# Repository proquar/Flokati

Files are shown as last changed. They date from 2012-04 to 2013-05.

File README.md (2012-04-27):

Flokati
=======

Flokati is a collaborative ad-hoc automation system consisting of a
(relatively) low-speed rf-part based on AVR-microcontrollers and Nordic's
NRF-ICs, an OpenWrt-based WiFi-Gateway and an Android-App as a frontend.

For convenience the Android-App and OpenWrt-package for ar71xx are provided
in binary too.

History / Motivation / Overview
===============================

The original idea was to build a system of battery-powered devices for off-
the-grid outdoor parties, it should be:
* absolutely easy to set up and to use
* fast and responsive
* used simultaneously by a few people (and be robust at that)
* relatively cheap to build

Overall it already works very well, it still has some shortcomings, but I am
working on those.

Flokati-Parts
-------------

**Devices**

*	Currently there are only some spotlights and a mirror ball motor that I
	built around the Atmega88 and NRF24L01+.
	Devices have a unique 64bit address and can have multiple controllable
	elements (e.g. brightness, speed).
	Devices use Nordic's proprietary 2.4GHz NRF-technology (which was chosen
	because it is really cheap, much cheaper than e.g. 802.15.4).

**Gateway**

*	There needs to be a bridge between the IP-world and the proprietary
	rf-world. Here it is an OpenWrt-based WiFi access point (a battery powered
	TP-Link MR11U in my case) that also acts as a DCHP-server and hosts the
	device database.

**Frontend**

*	At the moment there's only the Android-App, which discovers new devices,
	requests device metadata from the device database and allows low-level
	control of discovered devices.

Architecture
------------

On the IP-side Flokati makes heavy use of IP-multicast. The bridge and the
Android devices all join a multicast group, and changes on one Android device
are immediately visible on the others. All actions on either side (NRF and IP)
are as fast as possible broadcast to the other side.

Controllable devices broadcast notify-messages with their ID and current
settings regularly, which are received by the frontend. The frontend then looks
up metadata (like name and controllable sinks) for that device from a database
which is also distributed in a multicast group. (Though the database currently
runs on the OpenWrt gateway and is not yet distributed)

So it is also possible to have controllable devices on the IP-side, so there
are currently no implementations for this. I will also add a mechanism for
remote configuration of some devices in the near future.

Directories
===========

**/avr**

*	These are some small devices I have built, there's a spotlight, which is
	able to PWM-dim or strobe a led. A mirror ball motor with controllable
	speed and direction. And the serial<->NRF gateway that is attached to the
	OpenWrt router.
	I will add hardware schematics and board layouts later.

**/Flokati-android**

*	This is the Android App as an Eclipse project. It's tiny and without any
	additional libraries. 

**/json-db**

*	Device metadata currently used by the database server on the OpenWrt
	router. Temporary solution. Should be put into /etc/flokati/db.

**/linux/flokati**

*	This is the OpenWrt package, consisting of two server-executables (bridge
	and database) and an init-script. The bridge can indicate it's status with
	a LED, that can be configured in the init-script.

**/flokati/python**

*	A few python tools, that I used during development. They do the same as the
	C-servers for OpenWrt.

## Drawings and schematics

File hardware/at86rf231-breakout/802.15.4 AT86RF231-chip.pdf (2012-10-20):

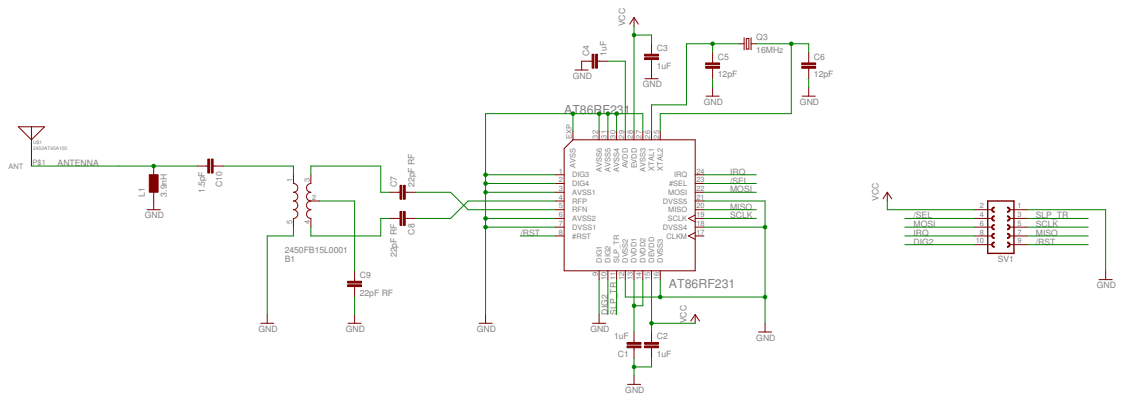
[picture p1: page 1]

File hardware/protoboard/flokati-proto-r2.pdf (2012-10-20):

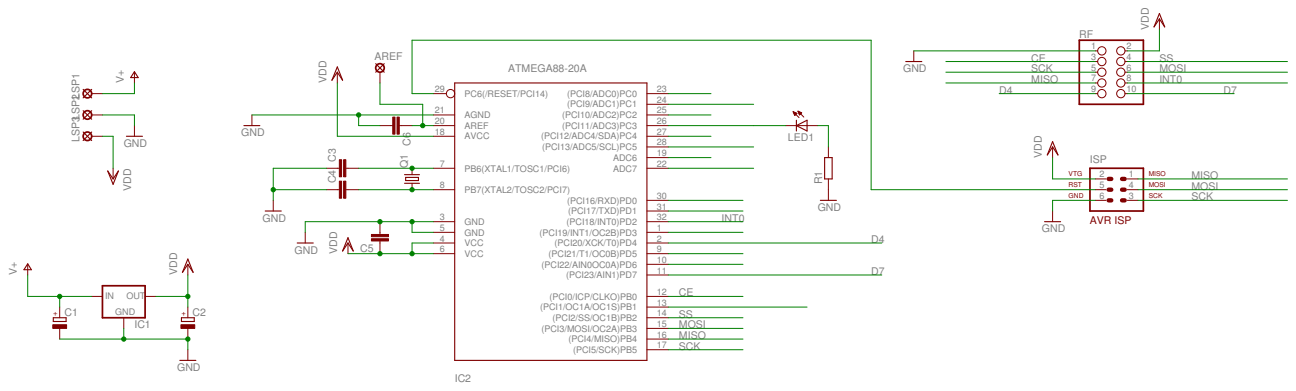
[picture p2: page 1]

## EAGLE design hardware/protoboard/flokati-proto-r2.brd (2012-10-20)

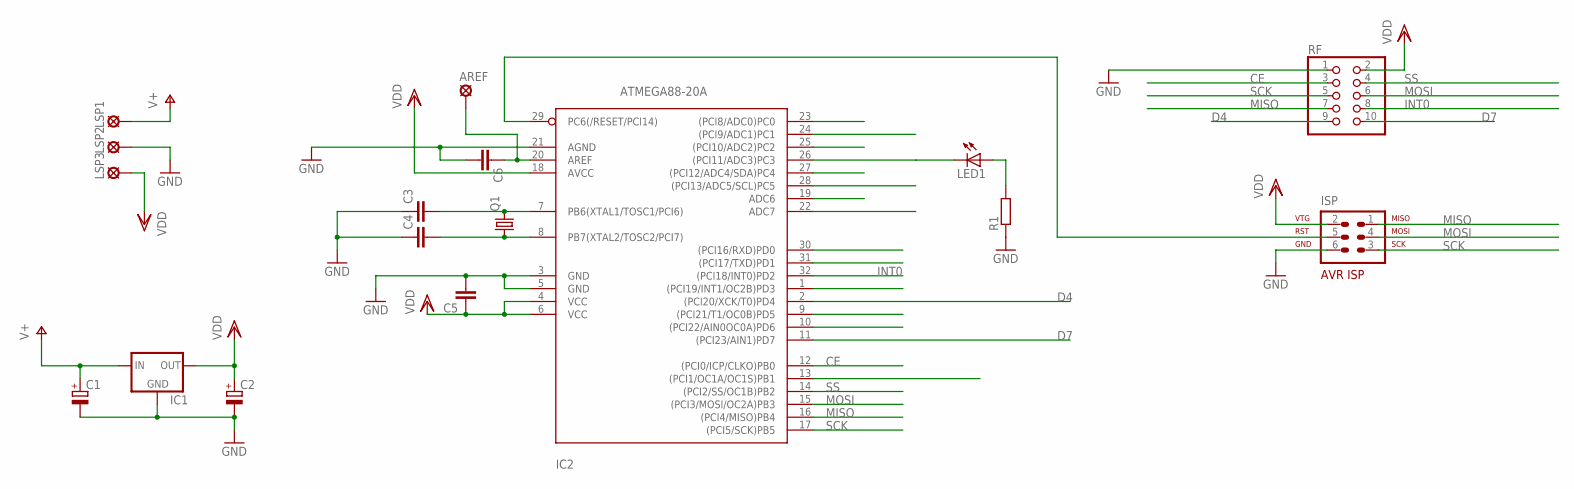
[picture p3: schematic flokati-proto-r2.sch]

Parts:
AREF: LSP10
C1, C2: CPOL-EUE2-4; E2-4
C3, C4, C5, C6: C-EUC0805K; C0805K
IC1: 78XXS
IC2: ATMEGA88-20A; TQFP32-08
ISP: AVR-ISP-6
LED1: LEDCHIP-LED0805; CHIP-LED0805
LSP1, LSP2, LSP3: LSP11
Q1: CRYSTALHC49U70; HC49U70
R1: R-EU_M0805; M0805
RF: PINHD-2X5; 2X05

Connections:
CE: IC2.12 ((PCI0/ICP/CLKO)PB0), RF.3
D4: IC2.2 ((PCI20/XCK/T0)PD4), RF.9
D7: IC2.11 ((PCI23/AIN1)PD7), RF.10
GND: C1.-, C2.-, C3.1, C4.1, C5.2, C6.2, IC1.GND, IC2.3 (GND), IC2.5 (GND), IC2.21 (AGND), ISP.6, LSP2.MP, R1.1, RF.1
INT0: IC2.32 ((PCI18/INT0)PD2), RF.8
MISO: IC2.16 ((PCI4/MISO)PB4), ISP.1, RF.7
MOSI: IC2.15 ((PCI3/MOSI/OC2A)PB3), ISP.4, RF.6
unnamed: C3.2, IC2.7 (PB6(XTAL1/TOSC1/PCI6)), Q1.2
unnamed: C4.2, IC2.8 (PB7(XTAL2/TOSC2/PCI7)), Q1.1
unnamed: AREF.MP, C6.1, IC2.20 (AREF)
unnamed: IC2.29 (PC6(/RESET/PCI14)), ISP.5
unnamed: IC2.26 ((PCI11/ADC3)PC3), LED1.C
unnamed: LED1.A, R1.2
SCK: IC2.17 ((PCI5/SCK)PB5), ISP.3, RF.5
SS: IC2.14 ((PCI2/SS/OC1B)PB2), RF.4
V+: C1.+, IC1.IN, LSP1.MP
VDD: C2.+, C5.1, IC1.OUT, IC2.4 (VCC), IC2.6 (VCC), IC2.18 (AVCC), ISP.2, LSP3.MP, RF.2

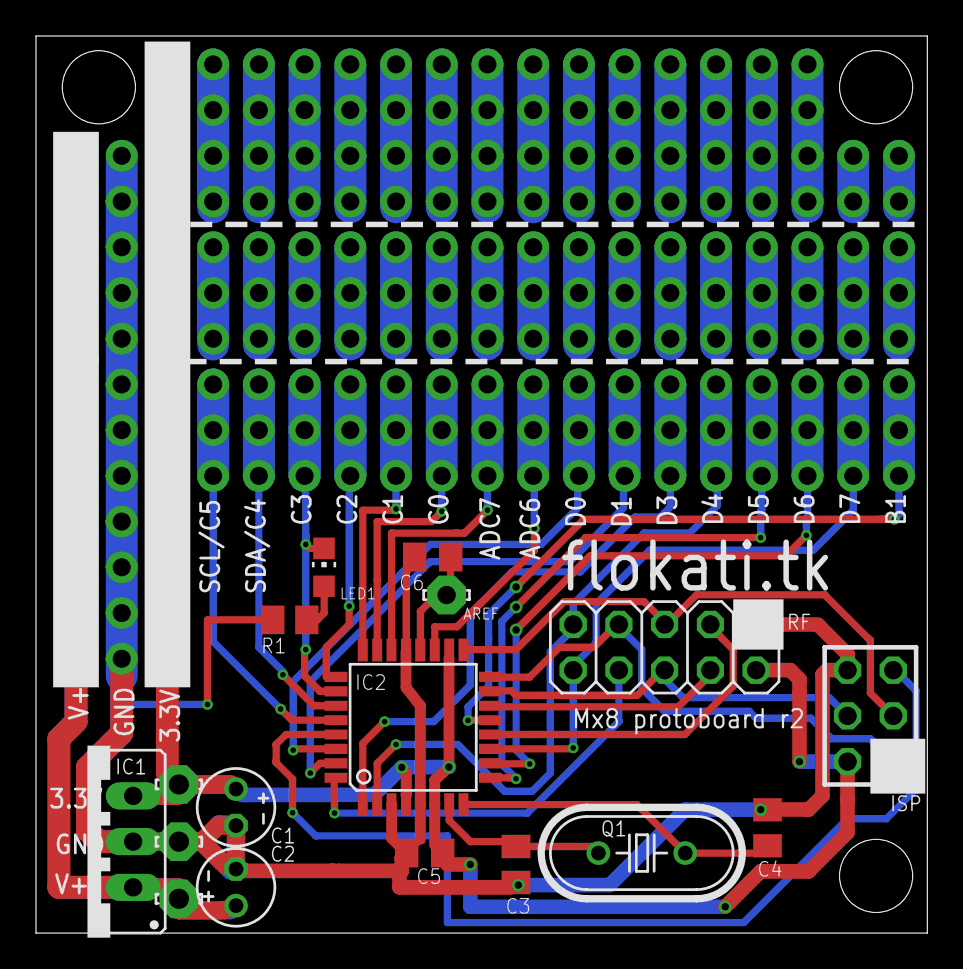
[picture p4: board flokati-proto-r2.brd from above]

Board: 2 copper layers, 49.5 x 49.8 mm, 17 parts (0 on the bottom side), 17 nets.

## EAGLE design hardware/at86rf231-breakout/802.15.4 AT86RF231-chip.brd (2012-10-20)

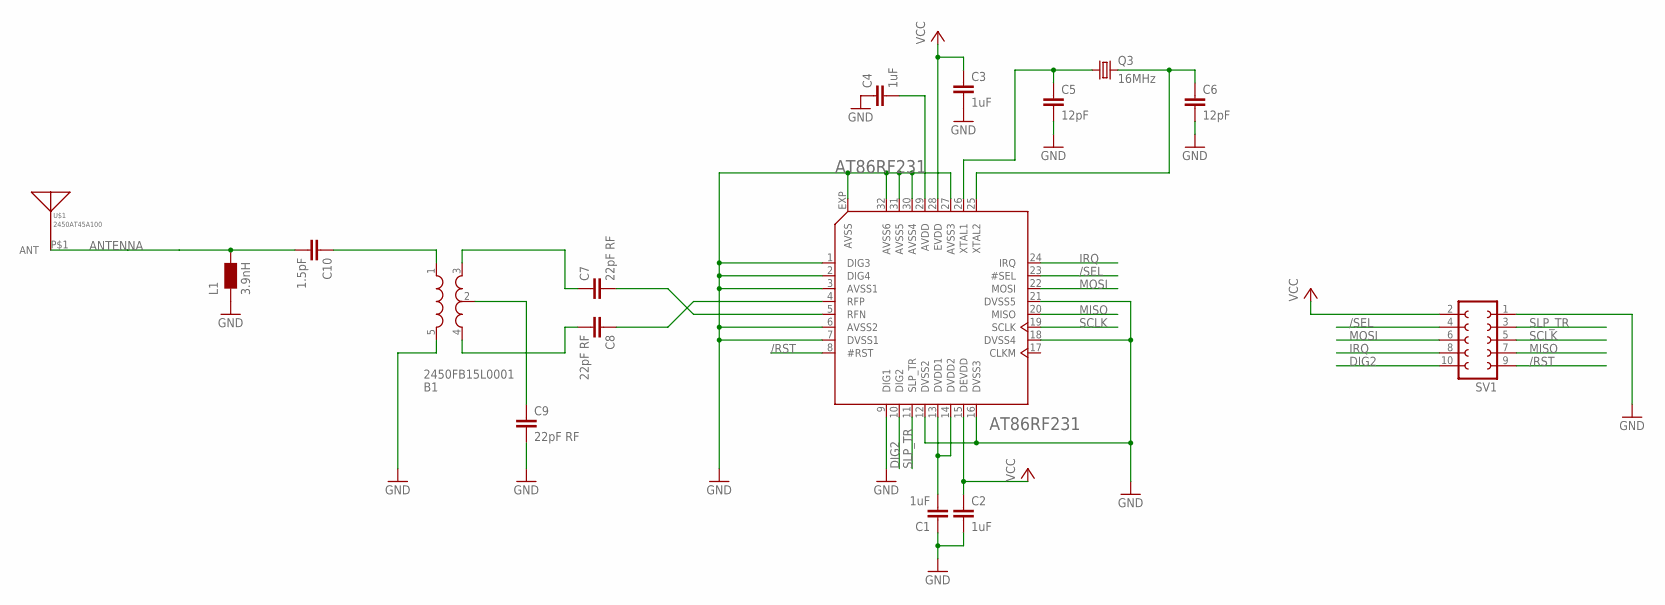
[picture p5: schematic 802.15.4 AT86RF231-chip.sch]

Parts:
AT86RF231: AT86RF231; QFN32
B1: 2450FB15L0001; BALUN
C1, C2, C3, C4: 1uF; C0402K
C5, C6: 12pF; C0402K
C7, C8, C9: 22pF RF; C0402K
C10: 1.5pF; C0402K
L1: 3.9nH; 0402
Q3: 16MHz; CTS406
SV1: FE05-2
U$1: 2450AT45A100

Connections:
/RST: AT86RF231.8 (#RST), SV1.9
/SEL: AT86RF231.23 (#SEL), SV1.4
ANTENNA: C10.2, L1.2, U$1.P$1
AVDD: AT86RF231.29 (AVDD), C4.2
DIG2: AT86RF231.10 (DIG2), SV1.10
DVDD1: AT86RF231.13 (DVDD1), AT86RF231.14 (DVDD2), C1.2
GND: AT86RF231.1 (DIG3), AT86RF231.2 (DIG4), AT86RF231.3 (AVSS1), AT86RF231.6 (AVSS2), AT86RF231.7 (DVSS1), AT86RF231.9 (DIG1), AT86RF231.12 (DVSS2), AT86RF231.16 (DVSS3), AT86RF231.18 (DVSS4), AT86RF231.21 (DVSS5), AT86RF231.27 (AVSS3), AT86RF231.30 (AVSS4), AT86RF231.31 (AVSS5), AT86RF231.32 (AVSS6), AT86RF231.EXP (AVSS), B1.5 (GND), C1.1, C2.2, C3.2, C4.1, C5.2, C6.2, C9.2, L1.1, SV1.1
IRQ: AT86RF231.24 (IRQ), SV1.8
MISO: AT86RF231.20 (MISO), SV1.7
MOSI: AT86RF231.22 (MOSI), SV1.6
unnamed: AT86RF231.26 (XTAL1), C5.1, Q3.1
unnamed: AT86RF231.25 (XTAL2), C6.1, Q3.3 (2)
unnamed: AT86RF231.4 (RFP), C8.1
unnamed: AT86RF231.5 (RFN), C7.2
unnamed: B1.3 (OUT1), C7.1
unnamed: B1.4 (OUT2), C8.2
unnamed: B1.2 (GND), C9.1
unnamed: B1.1 (IN), C10.1
SCLK: AT86RF231.19 (SCLK), SV1.5
SLP_TR: AT86RF231.11 (SLP_TR), SV1.3
VCC: AT86RF231.15 (DEVDD), AT86RF231.28 (EVDD), C2.1, C3.1, SV1.2

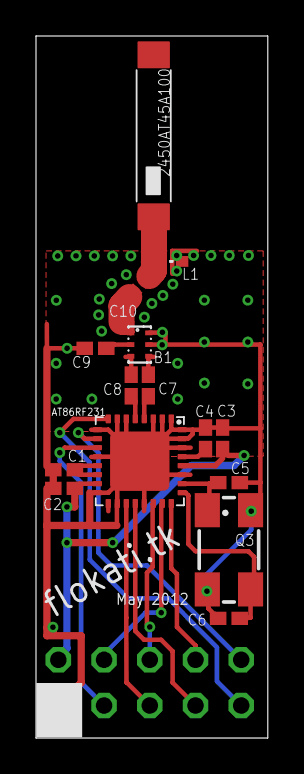
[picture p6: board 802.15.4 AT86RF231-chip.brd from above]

Board: 2 copper layers, 12.9 x 39.0 mm, 16 parts (1 on the bottom side), 21 nets.

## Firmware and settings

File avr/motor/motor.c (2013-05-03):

#include <avr/io.h>
#include <avr/interrupt.h>
#include <stdlib.h>

#include "../nrf24l01/packet.h"
#include "../nrf24l01/radio.h"
#include "../nrf24l01/common.h"

// motors have 2 sinks:
//   1: speed (16bit signed)
//   2: boost (boolean)

#define OWN_ADDRESS		"\0\0\0\x01\x00\x08\x00\x01"

// status-led
#define RXMON_INIT()	DDRC |= (1<<3)
#define RXMON_ON() 		DDRC |= (1<<3)
#define RXMON_OFF() 	DDRC &= ~(1<<3)

// Motor:	Dir1: D6, OC0A (dir1)
//			Dir2: D5, OC0B
//			EN:   C0
#define MOTOR_INIT()		PORTC&=~1; DDRC|=1; PORTD&=~((1<<5)|(1<<6)); DDRD|=((1<<5)|(1<<6))
#define MOTOR_ENABLE() 		PORTC|=1
#define MOTOR_DISABLE()		PORTC&=~1
#define MOTOR_FW_ON()		PORTD|=(1<<6)
#define MOTOR_FW_OFF()		PORTD&=~(1<<6)
#define MOTOR_RW_ON()		PORTD|=(1<<5)
#define MOTOR_RW_OFF()		PORTD&=~(1<<5)

radiopacket_t packet, notify;
volatile uint8_t newPacket=0;
volatile uint16_t nrf_reset_cnt=0;
volatile uint8_t notify_cnt=0;


volatile uint8_t direction=0;
volatile uint16_t speed=140;	// 140 = 1rpm, 230 = 2rpm, 300 = 3rpm, 370 = 4rpm,   max 500 @4.8V
volatile int16_t receivedSpeed=0;

volatile uint16_t pwmCnt=0;

volatile uint16_t boostCnt=0;
volatile int8_t boost=0;



void prepareNotify(void) {
	notify.type=NOTIFY;
	memcpy(notify.address, OWN_ADDRESS, 8);
	
	notify.data.notify.content[ 0]=0x01; //len: 2
	notify.data.notify.content[ 3]=0x02; //len: 1
	notify.data.notify.content[ 5]=0x03; //invalid sink
}
void sendNotify(void) {
	notify.data.notify.content[ 1]=receivedSpeed>>8;
	notify.data.notify.content[ 2]=receivedSpeed;
	notify.data.notify.content[ 4]=boost;
	
	Radio_Transmit(&notify, ABSOLUTE_MAXIMUM_SIZE, RADIO_WAIT_FOR_TX);
}


int main(void)
{
	RXMON_INIT();
	
	// STRATEGY:
	//     pwm is too fast for our motor, so we will just give it a short push twice a second
	//     so, we use the overflow interrupt to do our own very slow pwm
	MOTOR_INIT();
	TCCR0A = 0; 			// normal mode, no pwm
	TCCR0B = (1<<CS01);		// clk/8, enable counter
	TIMSK0 |= (1<<TOIE0);	//overflow interrupt on
	
	// Timer 2 for blinking status LED (clk/1024)
	TCCR2B = (1<<CS22)|(1<<CS21)|(1<<CS20);
	TIMSK2 |= (1<<TOIE2);
	
	// TImer 1 (clk/1024) for boost timing
	TCCR1B=(1<<CS12)|(1<<CS10);
	
	receivedSpeed=speed<<6;
	if (direction) speed *= -1;
	prepareNotify();
	
	rf_init();
	sei();

	for(;;) {		
		if ( newPacket ) {
			newPacket--;
			if ( Radio_Receive(&packet) >= RADIO_RX_MORE_PACKETS ) {
				RXMON_ON();
				
				// a real data package received
				if (packet.type==MESSAGE && (memcmp(packet.address, OWN_ADDRESS, 8)==0)) {
					
					uint8_t content_ptr=0;
					while (content_ptr<MESSAGE_CONTENT_MAX_SIZE) {
						uint8_t sink=packet.data.message.content[content_ptr];
						if (sink==1) {
							receivedSpeed = packet.data.message.content[content_ptr+1];
							receivedSpeed <<= 8;
							receivedSpeed |= packet.data.message.content[content_ptr+2];
							content_ptr+=3;
						} else if (sink==2) {
							if (packet.data.message.content[content_ptr+1] && boost<=0)
								boost = 1;
							//TODO: immediately reply with notify
							content_ptr+=2;
						} else {
							break;
						}
					}
					
					// ...
					if (receivedSpeed>=0) {
						speed=receivedSpeed>>6; //only use 9 bit (max. duty cycle 1/4)
						direction=0;
					} else {
						speed=(receivedSpeed*-1)>>6;
						direction=1;
					}
				}
			}
			
		}
		
		if (boost==-1) {
			// TODO send notify when boost is done
			boost=0;
		}
		
		if (nrf_reset_cnt>180) {
			// sometimes it seems that the nrf-chip crashes, so we re-initialise it after ~6s without receiving anything
			rf_init();
			nrf_reset_cnt=0;
		}
		
		if (notify_cnt>28) {
			sendNotify();
			notify_cnt=0;
		}
	}
	return 0;
}

ISR( TIMER0_OVF_vect ) {
	if (boost>0) {
		if (boost==1) {
			MOTOR_ENABLE();
			if (direction) { MOTOR_RW_OFF(); MOTOR_FW_ON(); }
			else { MOTOR_FW_OFF(); MOTOR_RW_ON(); }
			boostCnt=TCNT1;
			boost=2;
		}
		else if (boost==2 && (TCNT1-boostCnt)>7000) { // ~900ms
			MOTOR_DISABLE();
			MOTOR_FW_OFF();
			MOTOR_RW_OFF();
			boost=-1;
			pwmCnt=0x03ff;
		}
	}
	else {
		if (pwmCnt==0) {
			if (speed>0) {
				MOTOR_ENABLE();
				if (direction) { MOTOR_RW_OFF(); MOTOR_FW_ON(); }
				else { MOTOR_FW_OFF(); MOTOR_RW_ON(); }
			}
		}
		if (pwmCnt == speed) {
			MOTOR_DISABLE();
			MOTOR_FW_OFF();
			MOTOR_RW_OFF();
		}
		
		pwmCnt++;
		pwmCnt&=0x07ff; //2047 max
	}
}


ISR( TIMER2_OVF_vect ) {
	nrf_reset_cnt++;
	notify_cnt++;
	RXMON_OFF();
}

void radio_rxhandler(uint8_t pipe_number)
{
	nrf_reset_cnt=0;
	newPacket++;
}

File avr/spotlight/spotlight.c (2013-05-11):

#include <avr/io.h>
#include <avr/interrupt.h>
#include <stdlib.h>

#include "../nrf24l01/packet.h"
#include "../nrf24l01/radio.h"
#include "../nrf24l01/common.h"

// spotlights have 4 sinks:
//   1: brightness (16bit unsigned)
//   2: strobelight (boolean)
//   3: strobe length (16bit unsigned)
//   4: strobe spacing (16bit unsigned)

// White: 1
//#define OWN_ADDRESS		"\0\0\0\x01\x00\x01\x00\x01"

// White: 2
#define OWN_ADDRESS		"\0\0\0\x01\x00\x01\x00\x02"
	
// Green: 1
//#define OWN_ADDRESS		"\0\0\0\x01\x00\x02\x00\x01"

//#define INVERTED_PWM 1


// status-led
#define STATUS_INIT()	DDRC |= (1<<3)
#define STATUS_ON() 	DDRC |= (1<<3)
#define STATUS_OFF() 	DDRC &= ~(1<<3)

// status-led
// #define RXMON_INIT()	DDRC |= (1<<3)
// #define RXMON_ON() 		DDRC |= (1<<3)
// #define RXMON_OFF() 	DDRC &= ~(1<<3)


radiopacket_t packet, notify;
volatile uint8_t newPacket=0;
volatile uint16_t nrf_reset_cnt=0;
volatile uint8_t notify_cnt=0;

volatile uint16_t tBrightness=0xe000;
volatile uint8_t tStrobe=0;
volatile uint16_t tStrobeSpac=0x0900;
volatile uint16_t tStrobeLen=0x0900;



void prepareNotify(void) {
	notify.type=NOTIFY;
	memcpy(notify.address, OWN_ADDRESS, 8);
	
	notify.data.notify.content[ 0]=0x01;
// 	notify.data.notify.content[ 1]=tBrightness>>8;
// 	notify.data.notify.content[ 2]=tBrightness;
	notify.data.notify.content[ 3]=0x02;
// 	notify.data.notify.content[ 4]=tStrobe;
	notify.data.notify.content[ 5]=0x03;
// 	notify.data.notify.content[ 6]=tStrobeLen>>8;
// 	notify.data.notify.content[ 7]=tStrobeLen;
	notify.data.notify.content[ 8]=0x04;
// 	notify.data.notify.content[ 9]=tStrobeSpac>>8;
// // 	notify.data.notify.content[10]=tStrobeSpac;
}
void sendNotify(void) {
// 	notify.data.notify.content[ 0]=0x01;
	notify.data.notify.content[ 1]=tBrightness>>8;
	notify.data.notify.content[ 2]=tBrightness;
// 	notify.data.notify.content[ 3]=0x02;
	notify.data.notify.content[ 4]=tStrobe;
// 	notify.data.notify.content[ 5]=0x03;
	notify.data.notify.content[ 6]=tStrobeLen>>8;
	notify.data.notify.content[ 7]=tStrobeLen;
// 	notify.data.notify.content[ 8]=0x04;
	notify.data.notify.content[ 9]=tStrobeSpac>>8;
	notify.data.notify.content[10]=tStrobeSpac;
	
	Radio_Transmit(&notify, ABSOLUTE_MAXIMUM_SIZE, RADIO_WAIT_FOR_TX);
}


int main(void)
{
	uint8_t commitChanges=0;
	
	STATUS_INIT();
	
	// Initialize Timer1 for PWM on OC1A with maximum frequency and 10bit -> 7.8kHz PWM
	#ifdef INVERTED_PWM
		TCCR1A = (1<<COM1A1)|(1<<COM1A0)|(1<<WGM11)|(1<<WGM10);
	#else
		TCCR1A = (1<<COM1A1)|(1<<WGM11)|(1<<WGM10);
	#endif
	
	TCCR1B = (1<<WGM12)|(1<<CS10); //no prescaler
	OCR1A=tBrightness>>6;
	DDRB |= (1<<1);
	PORTB |= (1<<1);
	
	// Timer 2 for blinking status LED (clk/1024)
	TCCR2B = (1<<CS22)|(1<<CS21)|(1<<CS20);
	TIMSK2 |= (1<<TOIE2);
	
	prepareNotify();
	
	rf_init();
	sei();

	for(;;) {
// 		sendNotify();
// 		DDRC ^= (1<<2);
// 		_delay_ms(700);
// 		Radio_Receive(&packet);
// 		Radio_Receive(&packet);
		
		
		if ( newPacket ) {
			newPacket--;
			if ( Radio_Receive(&packet) >= RADIO_RX_MORE_PACKETS ) {
				
				// a real data package received
				if (packet.type==MESSAGE && (memcmp(packet.address, OWN_ADDRESS, 8)==0)) {
					STATUS_ON();
					
					cli();
					uint8_t content_ptr=0;
					while (content_ptr<MESSAGE_CONTENT_MAX_SIZE) {
						uint8_t sink=packet.data.message.content[content_ptr];
						if (sink==1) {
							tBrightness = packet.data.message.content[content_ptr+1];
							tBrightness <<= 8;
							tBrightness |= packet.data.message.content[content_ptr+2];
							content_ptr+=3;
							commitChanges=1;
						} else if (sink==2) {
							tStrobe = packet.data.message.content[content_ptr+1];
							content_ptr+=2;
							commitChanges=1;
						} else if (sink==3) {
							tStrobeLen = packet.data.message.content[content_ptr+1];
							tStrobeLen <<= 8;
							tStrobeLen |= packet.data.message.content[content_ptr+2];
							content_ptr+=3;
							commitChanges=1;
						} else if (sink==4) {
							tStrobeSpac = packet.data.message.content[content_ptr+1];
							tStrobeSpac <<= 8;
							tStrobeSpac |= packet.data.message.content[content_ptr+2];
							content_ptr+=3;
							commitChanges=1;
						} else {
							break;
						}
					}
					sei();
					
					if (commitChanges) {
						commitChanges=0;
						if (tStrobe) {
							
							#ifdef INVERTED_PWM
								TCCR1A = (1<<COM1A1)|(1<<COM1A0)|(1<<WGM11);		// prescaler 256, ICR1 max
							#else
								TCCR1A = (1<<COM1A1)|(1<<WGM11);
							#endif
							TCCR1B = (1<<WGM13)|(1<<WGM12)|(1<<CS12);
							
							OCR1A = tStrobeLen>>1;
							ICR1 = (tStrobeLen>>1) + (tStrobeSpac>>1);				// divide by 2, so we have a maximum of 2^16
							if (TCNT1>ICR1) TCNT1=0;
						}
						else {
							
							#ifdef INVERTED_PWM
								TCCR1A = (1<<COM1A1)|(1<<COM1A0)|(1<<WGM11)|(1<<WGM10);		// max frequency, 10 bit in counter 1
							#else
								TCCR1A = (1<<COM1A1)|(1<<WGM11)|(1<<WGM10);
							#endif
							TCCR1B = (1<<WGM12)|(1<<CS10);
							
							OCR1A = tBrightness>>6; //dimming with 10 bit, so discard lower 6 bit
							if (TCNT1>1023) TCNT1=0;
							
						}
					}
				}
			}
			
		}
		
		if (nrf_reset_cnt>180) {
			// sometimes it seems that the nrf-chip crashes, so we re-initialise it after ~6s without receiving anything
			rf_init();
			nrf_reset_cnt=0;
		}
		
		if (notify_cnt>28) {
			sendNotify();
			notify_cnt=0;
		}
	}
	return 0;
}

ISR( TIMER2_OVF_vect ) {
	nrf_reset_cnt++;
	notify_cnt++;
	STATUS_OFF();
}

void radio_rxhandler(uint8_t pipe_number)
{
	nrf_reset_cnt=0;
	newPacket++;
}

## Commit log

2012-10-20 Added AT86RF231 Testprogram, protoboard rev. 2 design files and AT86RF231 breakout board (chip antenna version) design files. All tested and working.
    [802.15.4 AT86RF231-chip.brd, 802.15.4 AT86RF231-chip.sch, flokati-proto-r2.brd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]
2013-05-03 Fixed bug in Reception of UDP packets and conversion to JSON-object in Android App.
    [motor.c]
2013-05-11 Fixed a bug in the spotlight when switching from dimmed to strobe-mode New feature in spotlight: inverted or normal mode selectable with macro New stand-alone strobe controller for external flashes
    [spotlight.c, strobo.c]

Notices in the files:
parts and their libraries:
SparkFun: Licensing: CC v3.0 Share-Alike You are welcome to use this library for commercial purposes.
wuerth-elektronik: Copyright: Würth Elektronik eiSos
